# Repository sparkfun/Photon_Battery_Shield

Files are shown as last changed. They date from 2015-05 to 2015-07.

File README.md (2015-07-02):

SparkFun Photon Battery Shield
========================================

SparkFun Photon Battery Shield

[*SparkFun Photon Battery Shield (DEV-13626)*](https://www.sparkfun.com/products/13626)

The [SparkFun Photon Battery Shield](https://www.sparkfun.com/products/13231) provides you with an easy way to power your Photon module with a Lithium polymer battery. Not only can the Battery Shield power you Photon but you will also be able to charge a LiPo bettery through it as well. The board comes with a JST connector for your single cell LiPo battery and utilizes the Photons on-board micro-USB connector for the charge input.

This battery shield uses a MCP73831 for LiPo charging and a MAX1704X for fuel gauging.

Repository Contents
-------------------

* **/Hardware** - Eagle design files (.brd, .sch)
* **/Production** - Production panel files (.brd)
* **/Libraries** - Firmware library and example code for the Particle Photon.

Documentation
--------------
* **[Hookup Guide](https://learn.sparkfun.com/tutorials/photon-battery-shield-hookup-guide)** - Hardware overview and example code.

Product Versions
----------------
* [DEV-13626](https://www.sparkfun.com/products/13626)- V1.0 release of the Photon Battery Shield.

License Information
-------------------
This product is _**open source**_! 

The **hardware** is released under [Creative Commons ShareAlike 4.0 International](https://creativecommons.org/licenses/by-sa/4.0/).

The **code**  license can be found in the source directory.

Please use, reuse, and modify these files as you see fit. Please maintain attribution to SparkFun Electronics and release anything derivative under the same license.

Distributed as-is; no warranty is given.

- Your friends at SparkFun.

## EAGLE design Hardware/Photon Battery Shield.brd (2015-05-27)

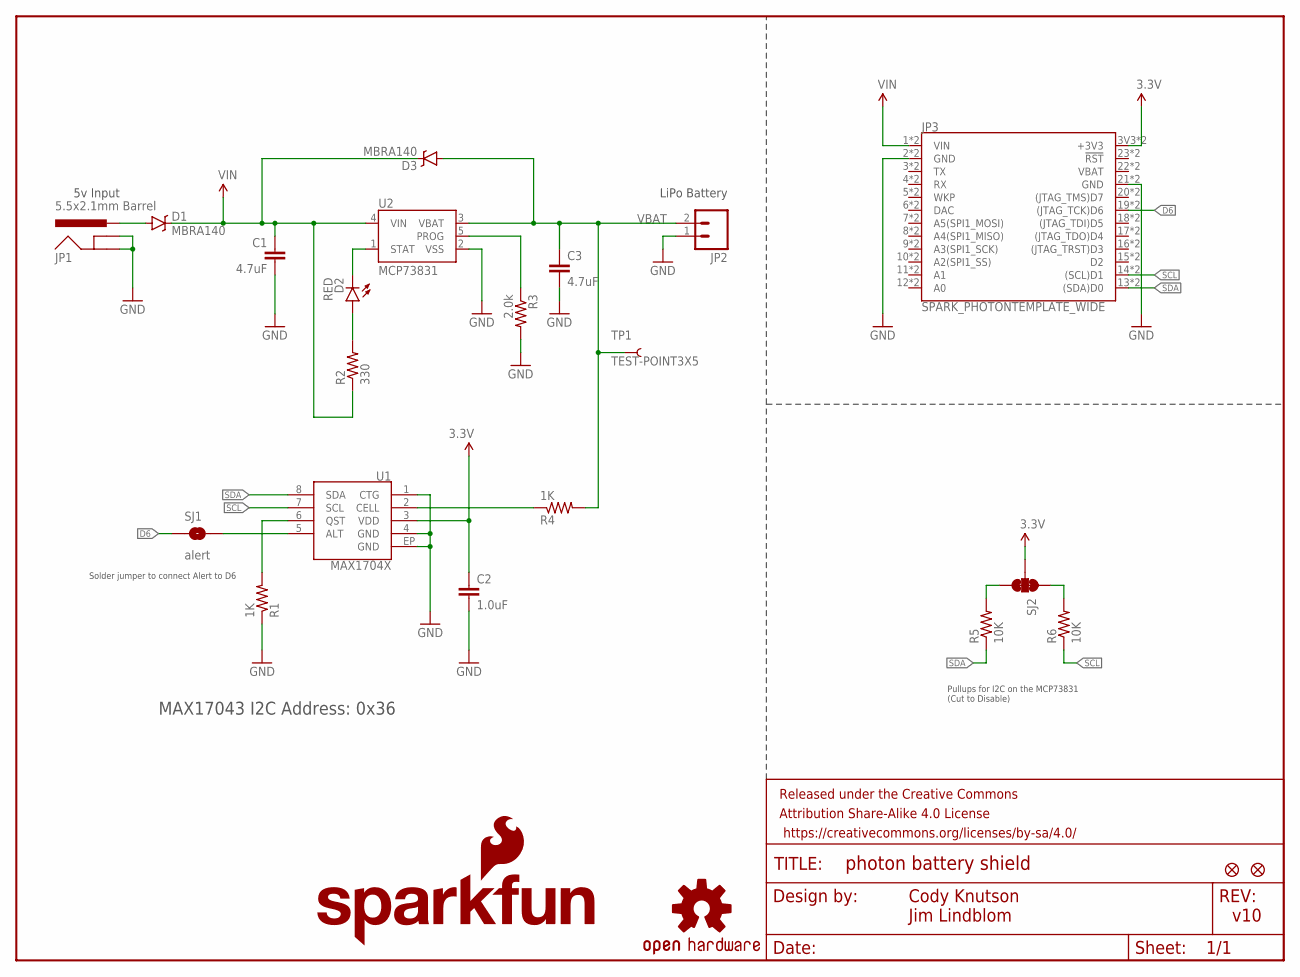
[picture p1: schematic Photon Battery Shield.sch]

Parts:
C1, C3: 4.7uF; 0603-CAP
C2: 1.0uF; 0603-CAP
D1, D3: MBRA140; SMA-DIODE
D2: RED; LED-0603
FID1, FID2: FIDUCIAL1X2; FIDUCIAL-1X2
FRAME1: FRAME-LETTER; CREATIVE_COMMONS
JP1: 5.5x2.1mm Barrel; POWER_JACK_SMD
JP2: M02-JST-2MM-SMT; JST-2-SMD
JP3: SPARK_PHOTONTEMPLATE_WIDE; SPARK_PHOTON_TEMPLATE_WIDE
LOGO2: OSHW-LOGOS; OSHW-LOGO-S
LOGO3: SFE_LOGO_NAME_FLAME.1_INCH; SFE_LOGO_NAME_FLAME_.1
R1, R4: 1K; 0603-RES
R2: 330; 0603-RES
R3: 2.0k; 0603-RES
R5, R6: 10K; 0603-RES
SJ1: alert; PAD-JUMPER-2-NO_YES_SILK
SJ2: JUMPER-PAD-3-NC_BY_TRACE; PAD-JUMPER-3-3OF3_NC_BY_TRACE_YES_SILK_FULL_BOX
TP1: TEST-POINT3X5; PAD.03X.05
U1: MAX1704X; TDFN-8
U2: MCP73831; SOT23-5

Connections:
3.3V: C2.1, JP3.3V3 (+3V3), JP3.24 (+3V3), SJ2.2, U1.3 (VDD)
D6: JP3.19 ((JTAG_TCK)D6), JP3.D6 ((JTAG_TCK)D6), SJ1.1
GND: C1.2, C2.2, C3.2, JP1.GND (GNDBREAK), JP1.P$4 (GND), JP2.1 (2), JP3.2 (GND), JP3.21 (GND), JP3.GND@0 (GND), JP3.GND@2 (GND), R1.1, R3.2, U1.1 (CTG), U1.4 (GND), U1.EP (GND), U2.2 (VSS)
unnamed: D2.A, R2.2
unnamed: D2.C, U2.1 (STAT)
unnamed: R3.1, U2.5 (PROG)
unnamed: SJ1.2, U1.5 (ALT)
unnamed: R4.1, U1.2 (CELL)
unnamed: R1.2, U1.6 (QST)
unnamed: R5.2, SJ2.3
unnamed: D1.A, JP1.VIN0 (PWR)
unnamed: R6.2, SJ2.1
SCL: JP3.14 ((SCL)D1), JP3.D1 ((SCL)D1), R6.1, U1.7 (SCL)
SDA: JP3.13 ((SDA)D0), JP3.D0 ((SDA)D0), R5.1, U1.8 (SDA)
VBAT: C3.1, D3.A, JP2.2 (1), R4.2, TP1.P$1, U2.3 (VBAT)
VIN: C1.1, D1.C, D3.C, JP3.1 (VIN), JP3.VIN, R2.1, U2.4 (VIN)

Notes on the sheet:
LiPo Battery
Cody Knutson Jim Lindblom
v10
MAX17043 I2C Address: 0x36
5v Input
Solder jumper to connect Alert to D6
Pullups for I2C on the MCP73831 (Cut to Disable)

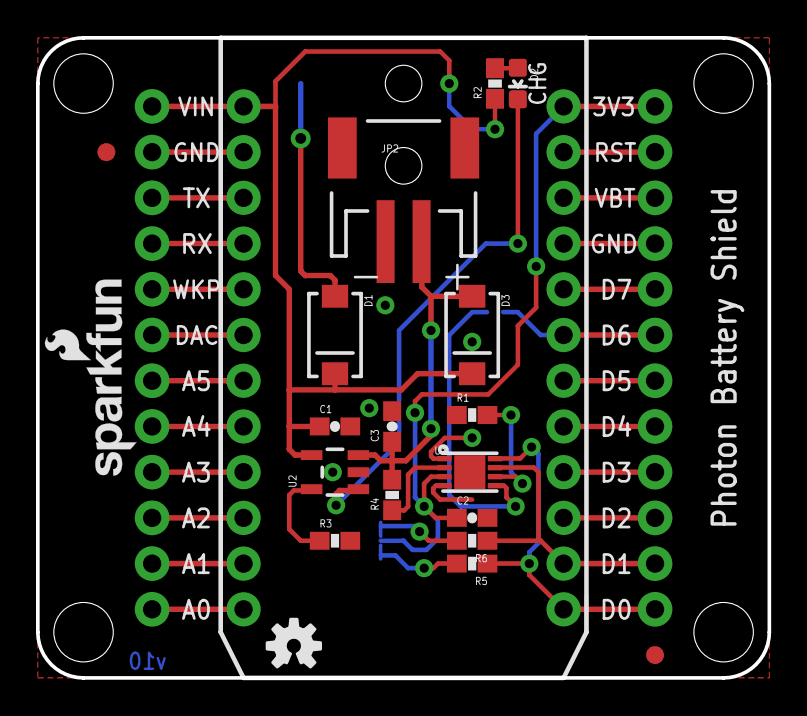
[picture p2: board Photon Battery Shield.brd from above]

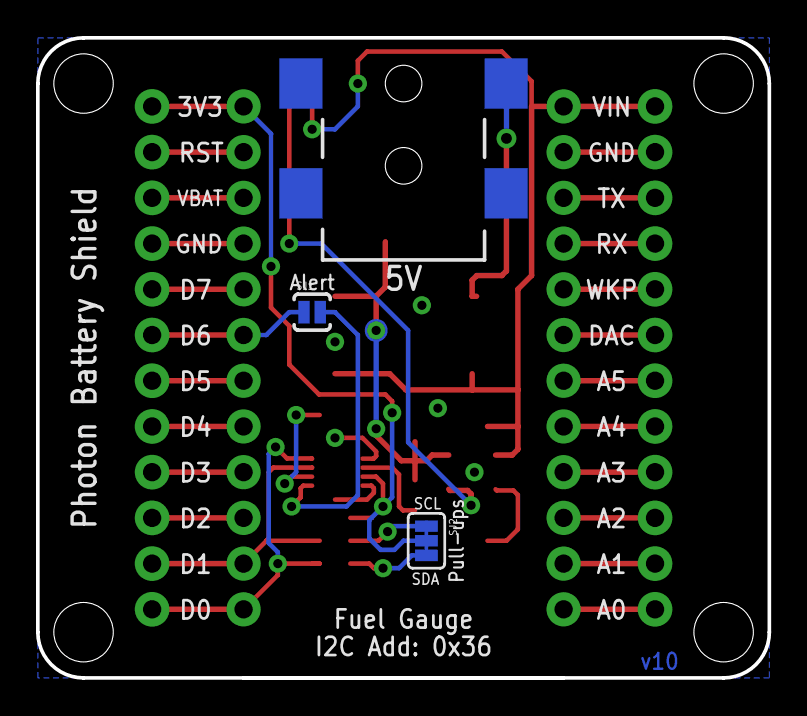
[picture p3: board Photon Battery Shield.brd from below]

Board: 2 copper layers, 40.6 x 35.6 mm, 25 parts (4 on the bottom side), 16 nets.

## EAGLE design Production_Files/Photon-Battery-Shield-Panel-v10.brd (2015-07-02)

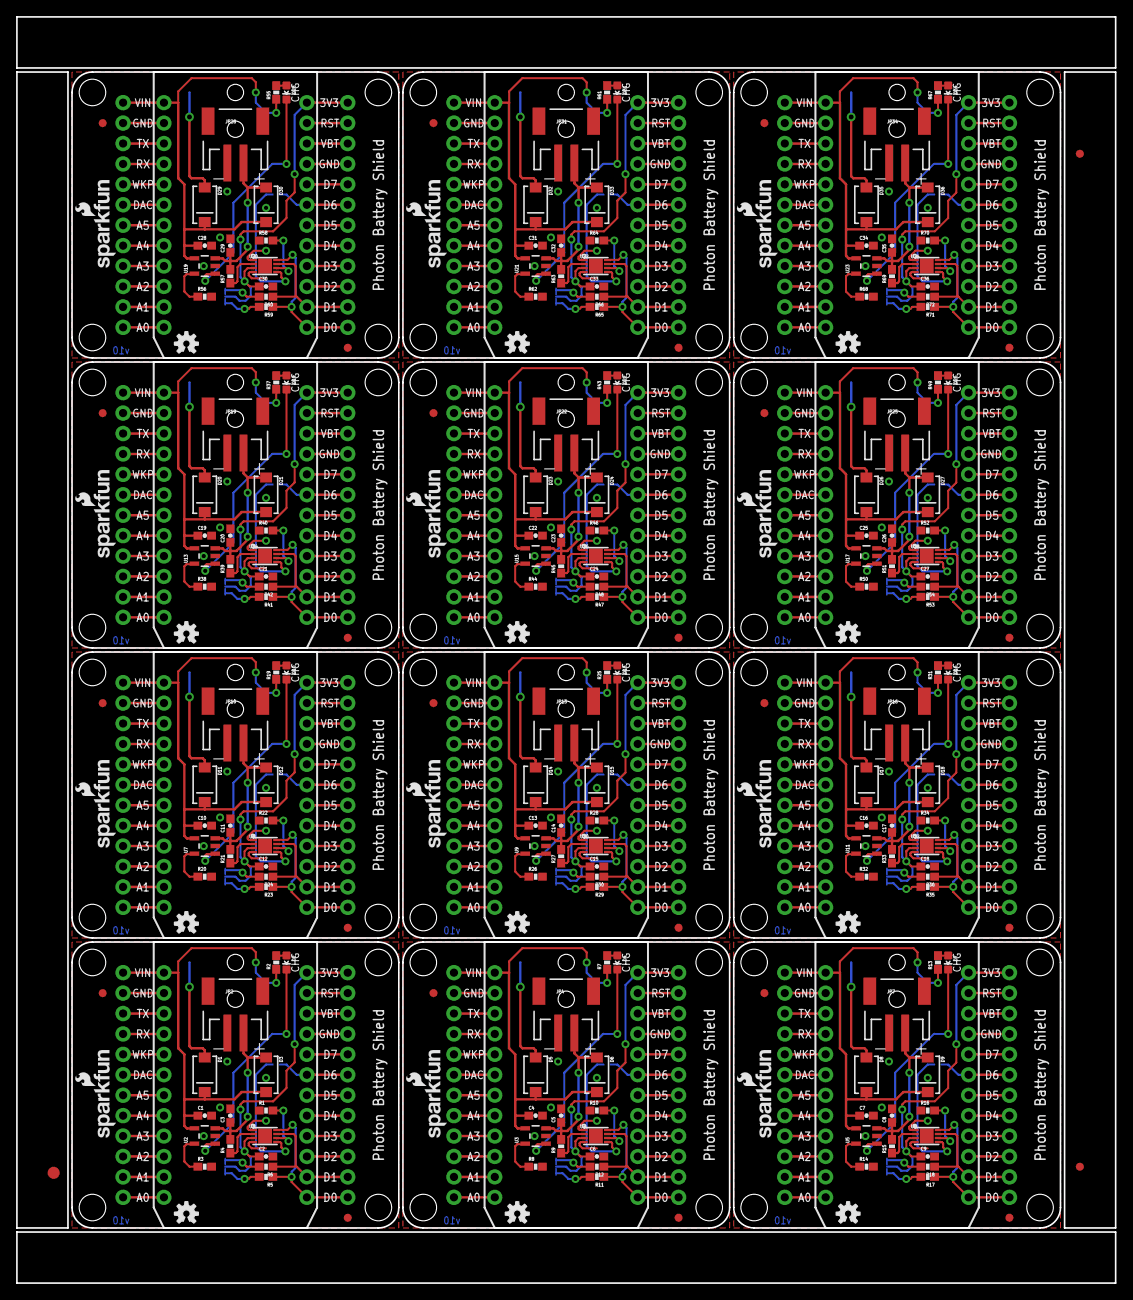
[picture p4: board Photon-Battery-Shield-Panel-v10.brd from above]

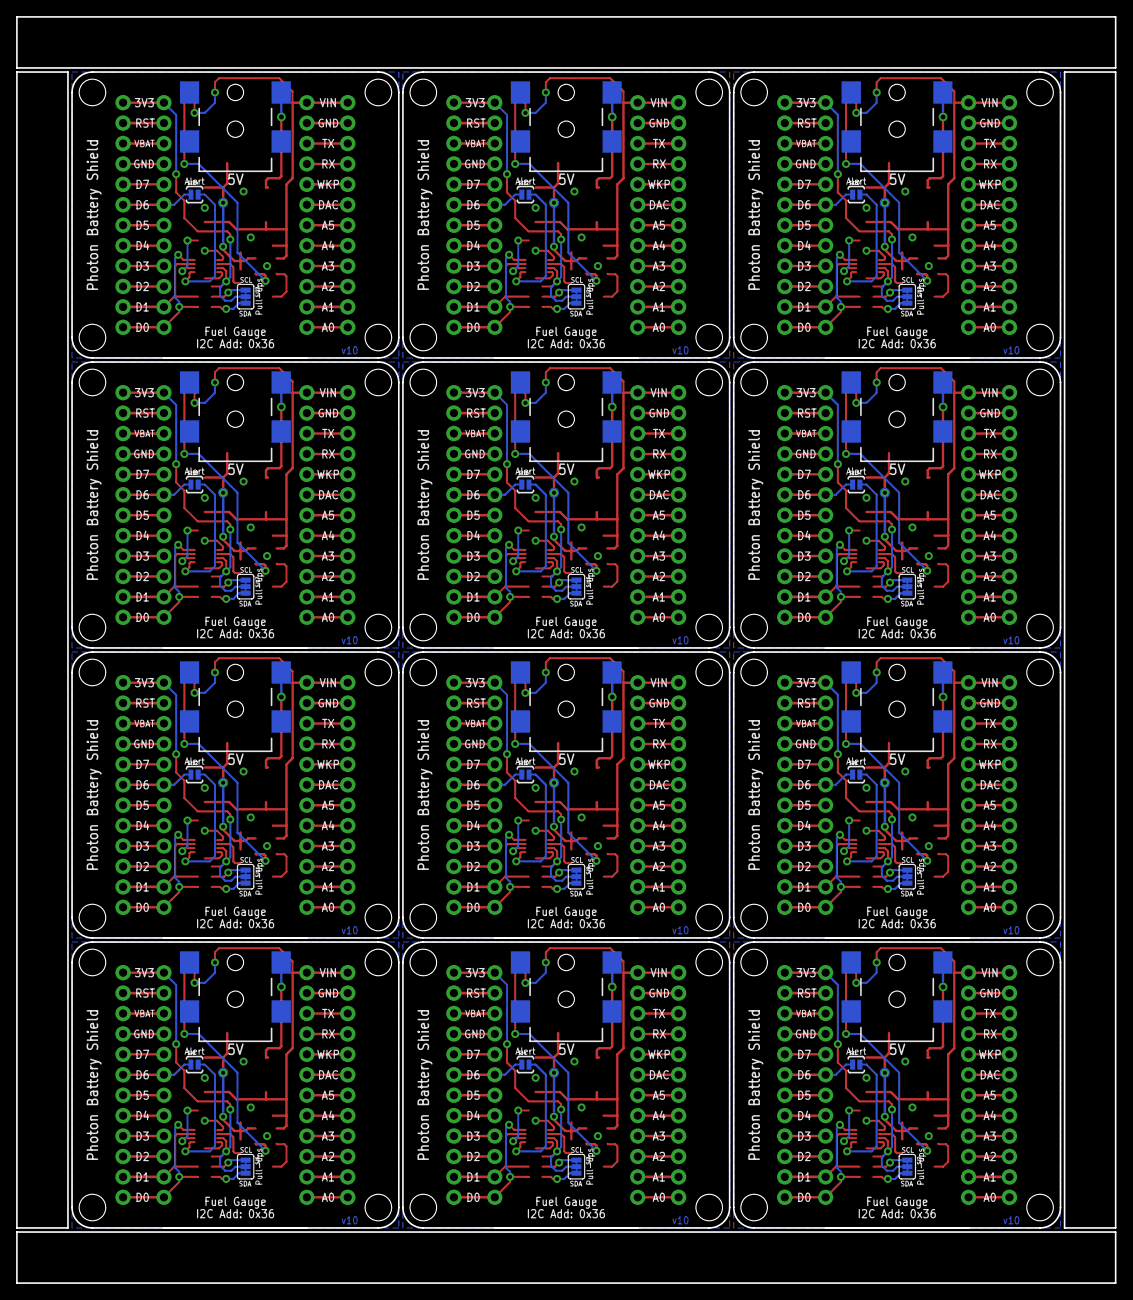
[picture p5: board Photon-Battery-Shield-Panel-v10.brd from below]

Board: 2 copper layers, 136.7 x 157.5 mm, 291 parts (48 on the bottom side), 192 nets.

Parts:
C1, C3, C4, C5, C7, C8, C10, C11, C13, C14, C16, C17, C19, C20, C22, C23, C25, C26, C28, C29, C31, C32, C34, C35: 4.7uF; 0603-CAP
C2, C6, C9, C12, C15, C18, C21, C24, C27, C30, C33, C36: 1.0uF; 0603-CAP
D1, D3, D5, D6, D8, D9, D11, D12, D14, D15, D17, D18, D20, D21, D23, D24, D26, D27, D29, D30, D32, D33, D35, D36: MBRA140; SMA-DIODE
D2, D4, D7, D10, D13, D16, D19, D22, D25, D28, D31, D34: RED; LED-0603
E$1: FIDUCIAL-1.5X3
E$4, E$5: FIDUCIAL-1X2
FID1, FID2, FID3, FID4, FID5, FID6, FID7, FID8, FID9, FID10, FID11, FID12, FID13, FID14, FID15, FID16, FID17, FID18, FID19, FID20, FID21, FID22, FID23, FID24: FIDUCIAL1X2; FIDUCIAL-1X2
JP1, JP6, JP9, JP12, JP15, JP18, JP21, JP24, JP27, JP30, JP33, JP36: 5.5x2.1mm Barrel; POWER_JACK_SMD
JP2, JP4, JP7, JP10, JP13, JP16, JP19, JP22, JP25, JP28, JP31, JP34: JST-2-SMD
JP3, JP5, JP8, JP11, JP14, JP17, JP20, JP23, JP26, JP29, JP32, JP35: SPARK_PHOTONTEMPLATE_WIDE; SPARK_PHOTON_TEMPLATE_WIDE
LOGO1, LOGO2, LOGO5, LOGO7, LOGO9, LOGO11, LOGO13, LOGO15, LOGO17, LOGO19, LOGO21, LOGO23: OSHW-LOGOS; OSHW-LOGO-S
LOGO3, LOGO4, LOGO6, LOGO8, LOGO10, LOGO12, LOGO14, LOGO16, LOGO18, LOGO20, LOGO22, LOGO24: SFE_LOGO_NAME_FLAME.1_INCH; SFE_LOGO_NAME_FLAME_.1
R1, R4, R9, R10, R15, R16, R21, R22, R27, R28, R33, R34, R39, R40, R45, R46, R51, R52, R57, R58, R63, R64, R69, R70: 1K; 0603-RES
R2, R7, R13, R19, R25, R31, R37, R43, R49, R55, R61, R67: 330; 0603-RES
R3, R8, R14, R20, R26, R32, R38, R44, R50, R56, R62, R68: 2.0k; 0603-RES
R5, R6, R11, R12, R17, R18, R23, R24, R29, R30, R35, R36, R41, R42, R47, R48, R53, R54, R59, R60, R65, R66, R71, R72: 10K; 0603-RES
SJ1, SJ4, SJ6, SJ8, SJ10, SJ12, SJ14, SJ16, SJ18, SJ20, SJ22, SJ24: alert; PAD-JUMPER-2-NO_YES_SILK
SJ2, SJ3, SJ5, SJ7, SJ9, SJ11, SJ13, SJ15, SJ17, SJ19, SJ21, SJ23: PAD-JUMPER-3-3OF3_NC_BY_TRACE_YES_SILK_FULL_BOX
TP1, TP2, TP3, TP4, TP5, TP6, TP7, TP8, TP9, TP10, TP11, TP12: TEST-POINT3X5; PAD.03X.05
U1, U4, U6, U8, U10, U12, U14, U16, U18, U20, U22, U24: MAX1704X; TDFN-8
U2, U3, U5, U7, U9, U11, U13, U15, U17, U19, U21, U23: MCP73831; SOT23-5

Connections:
3.3V: C2.1, JP3.3V3, JP3.24, SJ2.2, U1.3
3.3V1: C6.1, JP5.3V3, JP5.24, SJ3.2, U4.3
3.3V2: C9.1, JP8.3V3, JP8.24, SJ5.2, U6.3
3.3V3: C12.1, JP11.3V3, JP11.24, SJ7.2, U8.3
3.3V4: C15.1, JP14.3V3, JP14.24, SJ9.2, U10.3
3.3V5: C18.1, JP17.3V3, JP17.24, SJ11.2, U12.3
3.3V6: C21.1, JP20.3V3, JP20.24, SJ13.2, U14.3
3.3V7: C24.1, JP23.3V3, JP23.24, SJ15.2, U16.3
3.3V8: C27.1, JP26.3V3, JP26.24, SJ17.2, U18.3
3.3V9: C30.1, JP29.3V3, JP29.24, SJ19.2, U20.3
3.3V10: C33.1, JP32.3V3, JP32.24, SJ21.2, U22.3
3.3V11: C36.1, JP35.3V3, JP35.24, SJ23.2, U24.3
D1: JP5.19, JP5.D6, SJ4.1
D2: JP8.19, JP8.D6, SJ6.1
D3: JP11.19, JP11.D6, SJ8.1
D4: JP14.19, JP14.D6, SJ10.1
D5: JP17.19, JP17.D6, SJ12.1
D6: JP3.19, JP3.D6, SJ1.1
D7: JP20.19, JP20.D6, SJ14.1
D8: JP23.19, JP23.D6, SJ16.1
D9: JP26.19, JP26.D6, SJ18.1
D10: JP29.19, JP29.D6, SJ20.1
D11: JP32.19, JP32.D6, SJ22.1
D12: JP35.19, JP35.D6, SJ24.1
GND: C1.2, C2.2, C3.2, JP1.GND, JP1.P$4, JP2.1, JP3.2, JP3.21, JP3.GND@0, JP3.GND@2, R1.1, R3.2, U1.1, U1.4, U1.EP, U2.2
GND1: C4.2, C5.2, C6.2, JP4.1, JP5.2, JP5.21, JP5.GND@0, JP5.GND@2, JP6.GND, JP6.P$4, R8.2, R10.1, U3.2, U4.1, U4.4, U4.EP
GND2: C7.2, C8.2, C9.2, JP7.1, JP8.2, JP8.21, JP8.GND@0, JP8.GND@2, JP9.GND, JP9.P$4, R14.2, R16.1, U5.2, U6.1, U6.4, U6.EP
GND3: C10.2, C11.2, C12.2, JP10.1, JP11.2, JP11.21, JP11.GND@0, JP11.GND@2, JP12.GND, JP12.P$4, R20.2, R22.1, U7.2, U8.1, U8.4, U8.EP
GND4: C13.2, C14.2, C15.2, JP13.1, JP14.2, JP14.21, JP14.GND@0, JP14.GND@2, JP15.GND, JP15.P$4, R26.2, R28.1, U9.2, U10.1, U10.4, U10.EP
GND5: C16.2, C17.2, C18.2, JP16.1, JP17.2, JP17.21, JP17.GND@0, JP17.GND@2, JP18.GND, JP18.P$4, R32.2, R34.1, U11.2, U12.1, U12.4, U12.EP
GND6: C19.2, C20.2, C21.2, JP19.1, JP20.2, JP20.21, JP20.GND@0, JP20.GND@2, JP21.GND, JP21.P$4, R38.2, R40.1, U13.2, U14.1, U14.4, U14.EP
GND7: C22.2, C23.2, C24.2, JP22.1, JP23.2, JP23.21, JP23.GND@0, JP23.GND@2, JP24.GND, JP24.P$4, R44.2, R46.1, U15.2, U16.1, U16.4, U16.EP
GND8: C25.2, C26.2, C27.2, JP25.1, JP26.2, JP26.21, JP26.GND@0, JP26.GND@2, JP27.GND, JP27.P$4, R50.2, R52.1, U17.2, U18.1, U18.4, U18.EP
GND9: C28.2, C29.2, C30.2, JP28.1, JP29.2, JP29.21, JP29.GND@0, JP29.GND@2, JP30.GND, JP30.P$4, R56.2, R58.1, U19.2, U20.1, U20.4, U20.EP
GND10: C31.2, C32.2, C33.2, JP31.1, JP32.2, JP32.21, JP32.GND@0, JP32.GND@2, JP33.GND, JP33.P$4, R62.2, R64.1, U21.2, U22.1, U22.4, U22.EP
GND11: C34.2, C35.2, C36.2, JP34.1, JP35.2, JP35.21, JP35.GND@0, JP35.GND@2, JP36.GND, JP36.P$4, R68.2, R70.1, U23.2, U24.1, U24.4, U24.EP
unnamed: D2.A, R2.2
unnamed: D2.C, U2.1
unnamed: R3.1, U2.5
unnamed: SJ1.2, U1.5
unnamed: R4.1, U1.2
unnamed: R1.2, U1.6
unnamed: R5.2, SJ2.3
unnamed: D1.A, JP1.VIN0
unnamed: R6.2, SJ2.1
unnamed: D4.A, R7.2
unnamed: D4.C, U3.1
unnamed: R8.1, U3.5
unnamed: R9.1, U4.2
unnamed: R10.2, U4.6
unnamed: SJ4.2, U4.5
unnamed: D5.A, JP6.VIN0
unnamed: R11.2, SJ3.3
unnamed: R12.2, SJ3.1
unnamed: D7.A, R13.2
unnamed: D7.C, U5.1
unnamed: R14.1, U5.5
unnamed: R15.1, U6.2
unnamed: R16.2, U6.6
unnamed: SJ6.2, U6.5
unnamed: D8.A, JP9.VIN0
unnamed: R17.2, SJ5.3
unnamed: R18.2, SJ5.1
unnamed: D10.A, R19.2
unnamed: D10.C, U7.1
unnamed: R20.1, U7.5
unnamed: R21.1, U8.2
unnamed: R22.2, U8.6
unnamed: SJ8.2, U8.5
unnamed: D11.A, JP12.VIN0
unnamed: R23.2, SJ7.3
unnamed: R24.2, SJ7.1
unnamed: D13.A, R25.2
unnamed: D13.C, U9.1
unnamed: R26.1, U9.5
unnamed: R27.1, U10.2
unnamed: R28.2, U10.6
unnamed: SJ10.2, U10.5
unnamed: D14.A, JP15.VIN0
unnamed: R29.2, SJ9.3
unnamed: R30.2, SJ9.1
unnamed: D16.A, R31.2
unnamed: D16.C, U11.1
unnamed: R32.1, U11.5
unnamed: R33.1, U12.2
unnamed: R34.2, U12.6
unnamed: SJ12.2, U12.5
unnamed: D17.A, JP18.VIN0
unnamed: R35.2, SJ11.3
unnamed: R36.2, SJ11.1
unnamed: D19.A, R37.2
unnamed: D19.C, U13.1
unnamed: R38.1, U13.5
unnamed: R39.1, U14.2
unnamed: R40.2, U14.6
unnamed: SJ14.2, U14.5
unnamed: D20.A, JP21.VIN0
unnamed: R41.2, SJ13.3
unnamed: R42.2, SJ13.1
unnamed: D22.A, R43.2
unnamed: D22.C, U15.1
unnamed: R44.1, U15.5
unnamed: R45.1, U16.2
unnamed: R46.2, U16.6
unnamed: SJ16.2, U16.5
unnamed: D23.A, JP24.VIN0
unnamed: R47.2, SJ15.3
unnamed: R48.2, SJ15.1
unnamed: D25.A, R49.2
unnamed: D25.C, U17.1
unnamed: R50.1, U17.5
unnamed: R51.1, U18.2
unnamed: R52.2, U18.6
unnamed: SJ18.2, U18.5
unnamed: D26.A, JP27.VIN0
unnamed: R53.2, SJ17.3
unnamed: R54.2, SJ17.1
unnamed: D28.A, R55.2
unnamed: D28.C, U19.1
unnamed: R56.1, U19.5
unnamed: R57.1, U20.2
unnamed: R58.2, U20.6
unnamed: SJ20.2, U20.5
unnamed: D29.A, JP30.VIN0
unnamed: R59.2, SJ19.3
unnamed: R60.2, SJ19.1
unnamed: D31.A, R61.2
unnamed: D31.C, U21.1
unnamed: R62.1, U21.5
unnamed: R63.1, U22.2
unnamed: R64.2, U22.6
unnamed: SJ22.2, U22.5
unnamed: D32.A, JP33.VIN0
unnamed: R65.2, SJ21.3
unnamed: R66.2, SJ21.1
unnamed: D34.A, R67.2
unnamed: D34.C, U23.1
unnamed: R68.1, U23.5
unnamed: R69.1, U24.2
unnamed: R70.2, U24.6
unnamed: SJ24.2, U24.5
unnamed: D35.A, JP36.VIN0
unnamed: R71.2, SJ23.3
unnamed: R72.2, SJ23.1
SCL: JP3.14, JP3.D1, R6.1, U1.7
SCL1: JP5.14, JP5.D1, R12.1, U4.7
SCL2: JP8.14, JP8.D1, R18.1, U6.7
SCL3: JP11.14, JP11.D1, R24.1, U8.7
SCL4: JP14.14, JP14.D1, R30.1, U10.7
SCL5: JP17.14, JP17.D1, R36.1, U12.7
SCL6: JP20.14, JP20.D1, R42.1, U14.7
SCL7: JP23.14, JP23.D1, R48.1, U16.7
SCL8: JP26.14, JP26.D1, R54.1, U18.7
SCL9: JP29.14, JP29.D1, R60.1, U20.7
SCL10: JP32.14, JP32.D1, R66.1, U22.7
SCL11: JP35.14, JP35.D1, R72.1, U24.7
SDA: JP3.13, JP3.D0, R5.1, U1.8
SDA1: JP5.13, JP5.D0, R11.1, U4.8
SDA2: JP8.13, JP8.D0, R17.1, U6.8
SDA3: JP11.13, JP11.D0, R23.1, U8.8
SDA4: JP14.13, JP14.D0, R29.1, U10.8
SDA5: JP17.13, JP17.D0, R35.1, U12.8
SDA6: JP20.13, JP20.D0, R41.1, U14.8
SDA7: JP23.13, JP23.D0, R47.1, U16.8
SDA8: JP26.13, JP26.D0, R53.1, U18.8
SDA9: JP29.13, JP29.D0, R59.1, U20.8
SDA10: JP32.13, JP32.D0, R65.1, U22.8
SDA11: JP35.13, JP35.D0, R71.1, U24.8
VBAT: C3.1, D3.A, JP2.2, R4.2, TP1.P$1, U2.3
VBAT1: C5.1, D6.A, JP4.2, R9.2, TP2.P$1, U3.3
VBAT2: C8.1, D9.A, JP7.2, R15.2, TP3.P$1, U5.3
VBAT3: C11.1, D12.A, JP10.2, R21.2, TP4.P$1, U7.3
VBAT4: C14.1, D15.A, JP13.2, R27.2, TP5.P$1, U9.3
VBAT5: C17.1, D18.A, JP16.2, R33.2, TP6.P$1, U11.3
VBAT6: C20.1, D21.A, JP19.2, R39.2, TP7.P$1, U13.3
VBAT7: C23.1, D24.A, JP22.2, R45.2, TP8.P$1, U15.3
VBAT8: C26.1, D27.A, JP25.2, R51.2, TP9.P$1, U17.3
VBAT9: C29.1, D30.A, JP28.2, R57.2, TP10.P$1, U19.3
VBAT10: C32.1, D33.A, JP31.2, R63.2, TP11.P$1, U21.3
VBAT11: C35.1, D36.A, JP34.2, R69.2, TP12.P$1, U23.3
VIN: C1.1, D1.C, D3.C, JP3.1, JP3.VIN, R2.1, U2.4
VIN1: C4.1, D5.C, D6.C, JP5.1, JP5.VIN, R7.1, U3.4
VIN2: C7.1, D8.C, D9.C, JP8.1, JP8.VIN, R13.1, U5.4
VIN3: C10.1, D11.C, D12.C, JP11.1, JP11.VIN, R19.1, U7.4
VIN4: C13.1, D14.C, D15.C, JP14.1, JP14.VIN, R25.1, U9.4
VIN5: C16.1, D17.C, D18.C, JP17.1, JP17.VIN, R31.1, U11.4
VIN6: C19.1, D20.C, D21.C, JP20.1, JP20.VIN, R37.1, U13.4
VIN7: C22.1, D23.C, D24.C, JP23.1, JP23.VIN, R43.1, U15.4
VIN8: C25.1, D26.C, D27.C, JP26.1, JP26.VIN, R49.1, U17.4
VIN9: C28.1, D29.C, D30.C, JP29.1, JP29.VIN, R55.1, U19.4
VIN10: C31.1, D32.C, D33.C, JP32.1, JP32.VIN, R61.1, U21.4
VIN11: C34.1, D35.C, D36.C, JP35.1, JP35.VIN, R67.1, U23.4

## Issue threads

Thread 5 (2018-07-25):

soc reading 256%

rdehooge, 2018-07-25:
I'm seeing the following output repeated from the MAX17043 LiPo Fuel Gauge.

Voltage: 5.12 V
Alert: 1
Percentage: 256.00 %

I haven't customized the system at all; just the Photon connected to the Sparkfun Photon Battery Shield and flashed the device with the MAX17043_Simple_Serial project. I've tried 0.7 and 0.8.0-rc.8 of the photon firmware.

rdehooge, 2018-07-25:
Make sure the battery is connected on startup..

Closed 2018-07-25.

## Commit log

2015-03-31 Added .BRD, and .SCH
    [Photon Battery Shield.brd, Photon Battery Shield.sch]
2015-04-01 Re-layed out, needs traces done
    [Photon Battery Shield.brd, Photon Battery Shield.sch]
2015-04-02 Adjusting VIN route, GND vias. Checklist stuff.
    - Adding measures
    - Adding PROD_ID to some parts
    - Re-routed ALERT pin to D6
    - Added MAx17043 i2c address to schematic
    - Labeled jumpers ("Pullups" and "Alert")
    - Routed traces from fuel gauge directly out of pads. (Added tRestrict to
    make sure GND traces didn't come out sides.)
    - Labeled LED "CHG"
    - Re-sized "5V" silk
    - Changed version number to "v01", added to b copper
    [Photon Battery Shield.brd, Photon Battery Shield.sch]
2015-04-08 Checklist Fixes
    (1) Added input voltage label on SCH
    (2) Added description for SJ1 in SCH
    (3) Added description for SJ2 in SCH
    (4) Fixed traces on R2, D1, and STAT pad on MCP
    (5) 3-way pull up now has SDA and SCL BPlace objects added next to the
    jumper
    (6) Resized Board Name text objects to prevent overlap with VBAT text
    object
    (7) "CHG" TPlace text, and the "Pull-ups" and "ALERT" BPlace text
    objects have been changed to Vector font type.
    [Photon Battery Shield.brd, Photon Battery Shield.sch]
2015-05-05 Connecting GND - Photon pin 21 - to the GND plane.
    [Photon Battery Shield.brd, Photon Battery Shield.sch]
2015-05-08 Updating Photon package to WIDE footprint. Defaulting SJ1 to open.
    [Photon Battery Shield.brd, Photon Battery Shield.sch]
2015-05-22 Fixing board name silk.
    [Photon Battery Shield.brd]
2015-05-22 Small silkscreen changes.
    [Photon Battery Shield.brd, Photon Battery Shield.sch]
2015-05-27 Adding test point to VBAT. Reducing bSilk on barrel jack to avoid going over board.
    [Photon Battery Shield.brd, Photon Battery Shield.sch]
2015-05-28 created panel v10
    [Photon-Battery-Shield-Panel-v10.brd]

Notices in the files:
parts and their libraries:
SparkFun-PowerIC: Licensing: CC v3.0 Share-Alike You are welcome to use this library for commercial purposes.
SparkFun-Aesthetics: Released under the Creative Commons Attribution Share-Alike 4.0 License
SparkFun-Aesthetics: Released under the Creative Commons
